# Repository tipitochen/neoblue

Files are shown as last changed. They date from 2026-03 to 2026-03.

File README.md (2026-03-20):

NEO BLUE : Direct PS5 Controller Interface for Neo Geo MVS
Nikita edition
NEO BLUE es un proyecto de hardware minimalista diseñado para habilitar el uso de mandos DualSense (PS5) en sistemas arcade SNK Neo Geo MVS.

A diferencia de otras interfaces complejas, NEO BLUE aprovecha la tolerancia de voltaje de los módulos ESP32 modernos para realizar una conexión directa y eficiente entre el Bluetooth HID y el estándar JAMMA/MVS, reduciendo la cantidad de componentes necesarios y simplificando el montaje.
Características del Proyecto:

    Conexión Directa (5V Compliant): Implementación optimizada para placas ESP32 con soporte de 5V, eliminando la necesidad de integrados de aislamiento externos.

    Dual-Core Multi-Player: Sistema de dos unidades ESP32 interconectadas por Serial (Pines 16/17) para habilitar controles independientes para Jugador 1 y Jugador 2.

    Baja Latencia: Basado en la librería Bluepad32, garantizando una respuesta casi instantánea ideal para juegos de lucha y acción.

    Interfaz Visual: Soporte para pantalla LCD 20x4 (I2C) que muestra el estado de emparejamiento, el nombre del proyecto ("NIKITA") y diagnósticos del sistema.

Ventajas de este enfoque:

    Menor Tamaño: El PCB o el cableado final es mucho más pequeño, ideal para integrar dentro de una carcasa de MVS o una Supergun.

    Simplicidad: Facilita que otros usuarios con conocimientos básicos de electrónica puedan replicar el proyecto rápidamente.

🛠️ Lista de Componentes (Bill of Materials)

Para replicar el proyecto NEO BLUE con soporte para dos jugadores y visualización de estado, necesitarás lo siguiente:
1. Microcontroladores

    2x ESP32 DevKit V1 (30 o 38 pines): Se utilizan dos unidades para gestionar ambos jugadores de forma independiente y garantizar la estabilidad del Bluetooth.

        Nota: Asegúrate de usar versiones modernas que soporten la lógica de 5V de los sistemas arcade en sus entradas/salidas.

2. Interfaz Visual

    1x Pantalla LCD 20x4 con módulo I2C: Para mostrar el estado de conexión de "Player 1" y "Player 2", además del nombre del proyecto.

        Dirección I2C común: 0x3F o 0x27.

3. Conectividad Arcade (Salidas)

    Cableado para peine JAMMA / Conector MVS: Cables para llevar las señales de los GPIO del ESP32 directamente a los pines de la placa Neo Geo.

        Direcciones: Arriba, Abajo, Izquierda, Derecha.

        Botones: A, B, C, D (y opcionalmente Select/Start).

4. Comunicación y Alimentación

    Cables de salto (Jumper Wires): Para la conexión Serial entre los dos ESP32 (Pines TX/RX 16 y 17) y la línea I2C del LCD.

    Fuente de alimentación de 5V: Puedes tomar los 5V directamente de la fuente de poder de tu sistema arcade o Supergun para alimentar los ESP32 y el LCD.

5. Periféricos (Mandos)

    1 o 2 Mandos Sony DualSense (PS5): Compatibles mediante la librería Bluepad32 integrada en el código.

Diagrama de conexiones :
<p align="center">
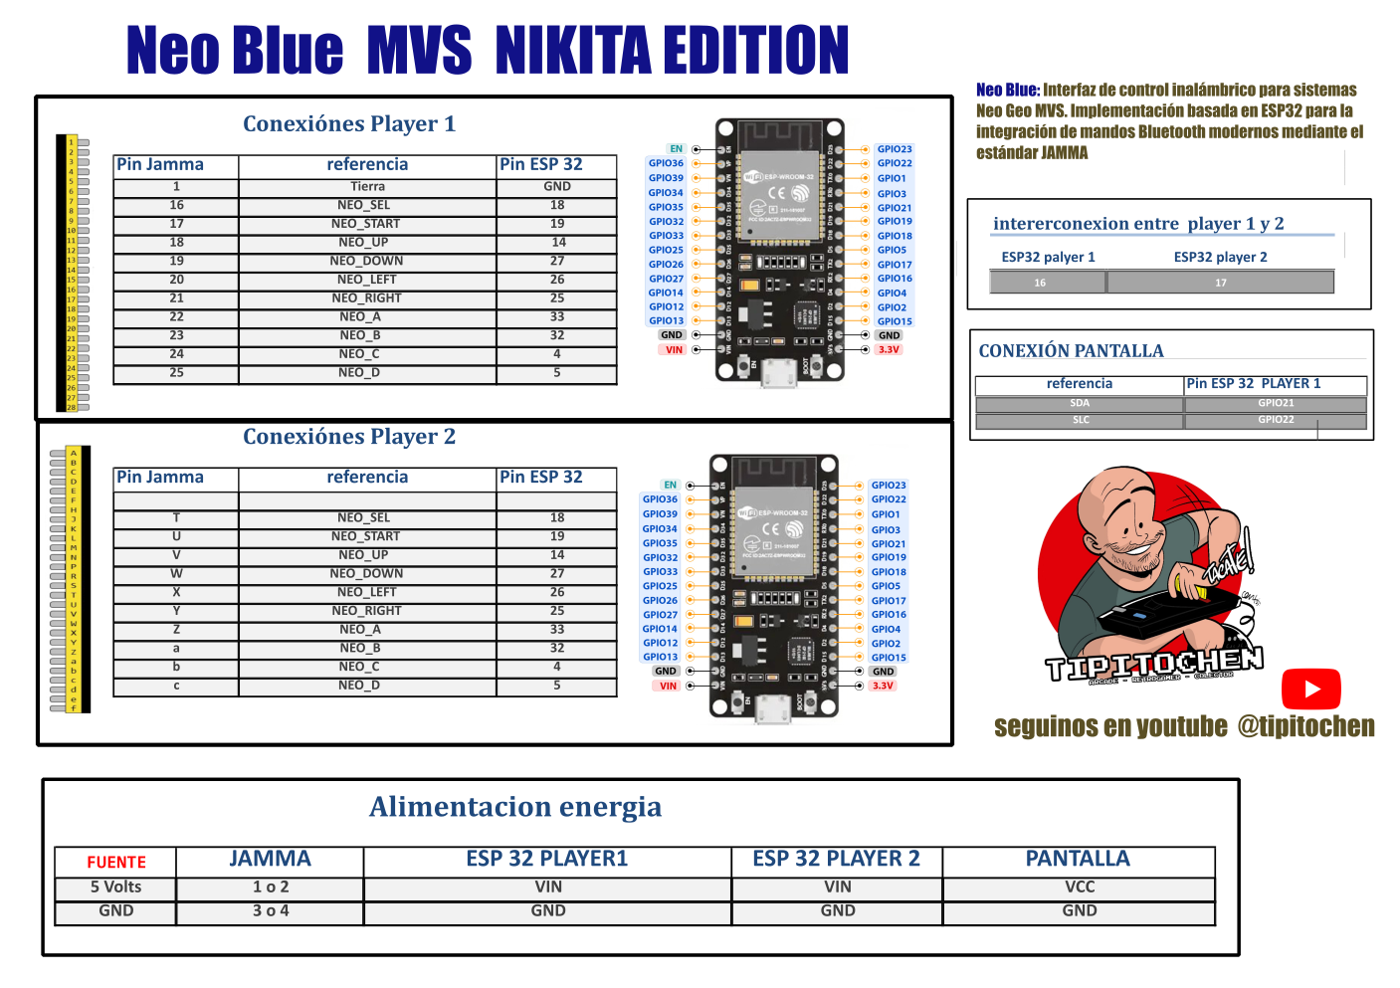
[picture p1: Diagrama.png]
Diagrama Neo Blue
  
</p>

💻 Software y Librerías Requeridas

Para compilar este proyecto en el IDE de Arduino, asegúrate de tener instaladas las siguientes dependencias:

    Bluepad32: La librería principal para la gestión de los mandos DualSense/PS5 vía Bluetooth.

    LiquidCrystal_I2C: Para el manejo de la pantalla LCD 20x4 (Dirección 0x3F).

    Wire.h: Librería estándar para la comunicación I2C entre el ESP32 y el display.

### 🤝 Agradecimientos
Este proyecto utiliza la excelente librería **[Bluepad32](https://github.com/ricardoquesada/bluepad32)** de **Ricardo Quesada**. Gracias a su trabajo en el stack de Bluetooth, es posible conectar mandos modernos a sistemas clásicos.
    
📸 Galería del Proyecto

| | |
|:---:|:---:|
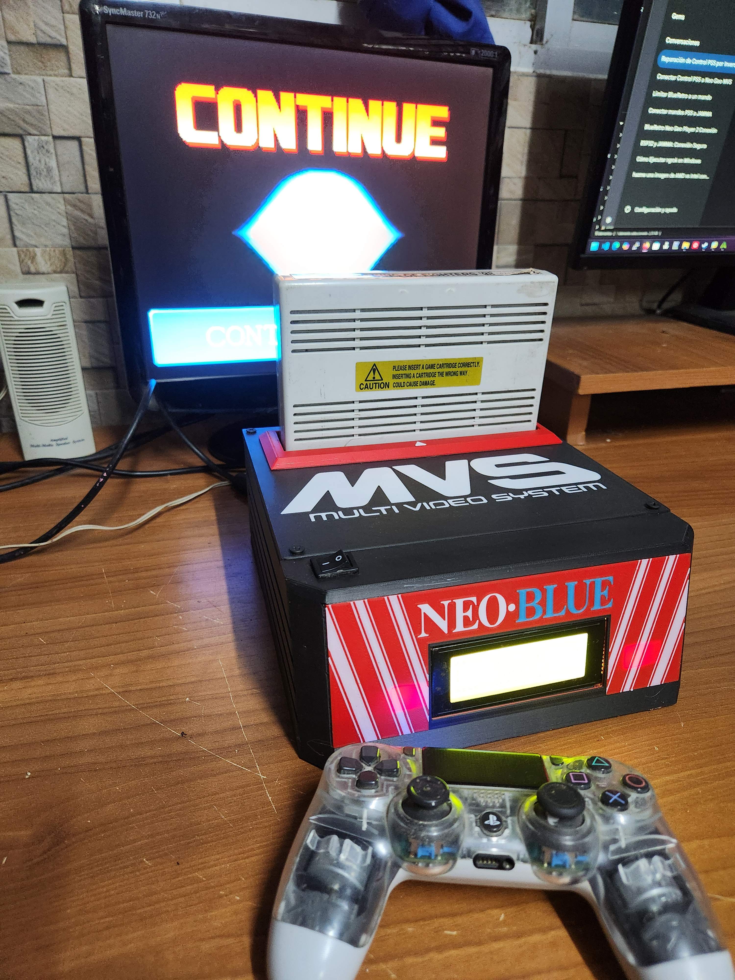
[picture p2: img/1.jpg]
Sistema en acción
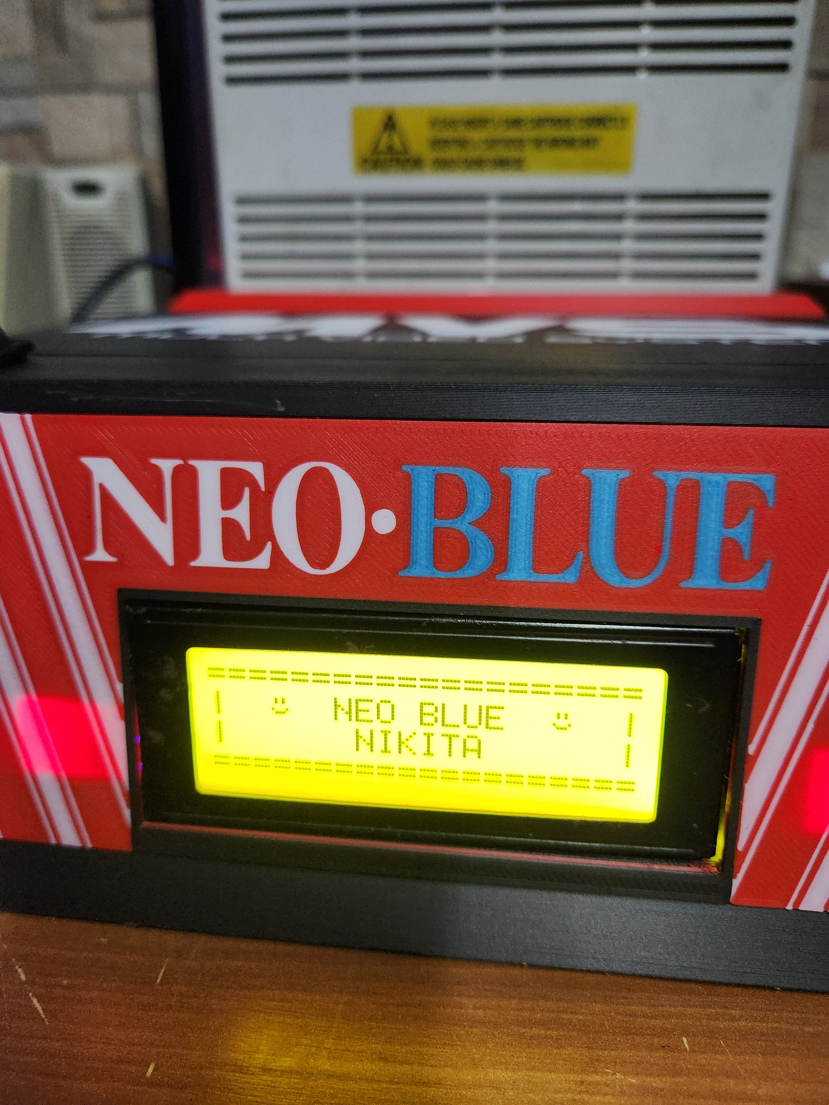
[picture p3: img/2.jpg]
Pantalla de Inicio
|  <br> **Setup Completo:** Consola MVS custom con mando DualSense. |  <br> **Bienvenida:** Interfaz LCD personalizada con el nombre **NIKITA**. |
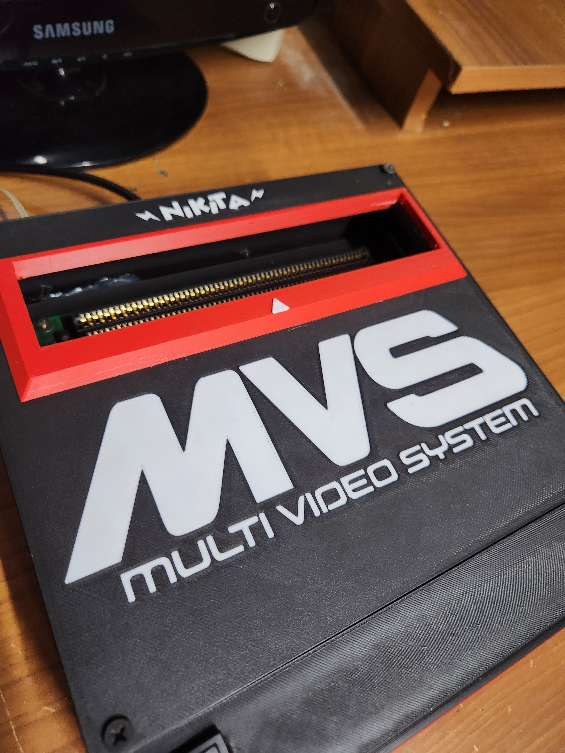
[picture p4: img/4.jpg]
Slot de Cartuchos
| Vista Superior <br> **Estética MVS:** Diseño frontal con colores clásicos de SNK. |  <br> **Detalle del Slot:** Acabado de la carcasa superior. |
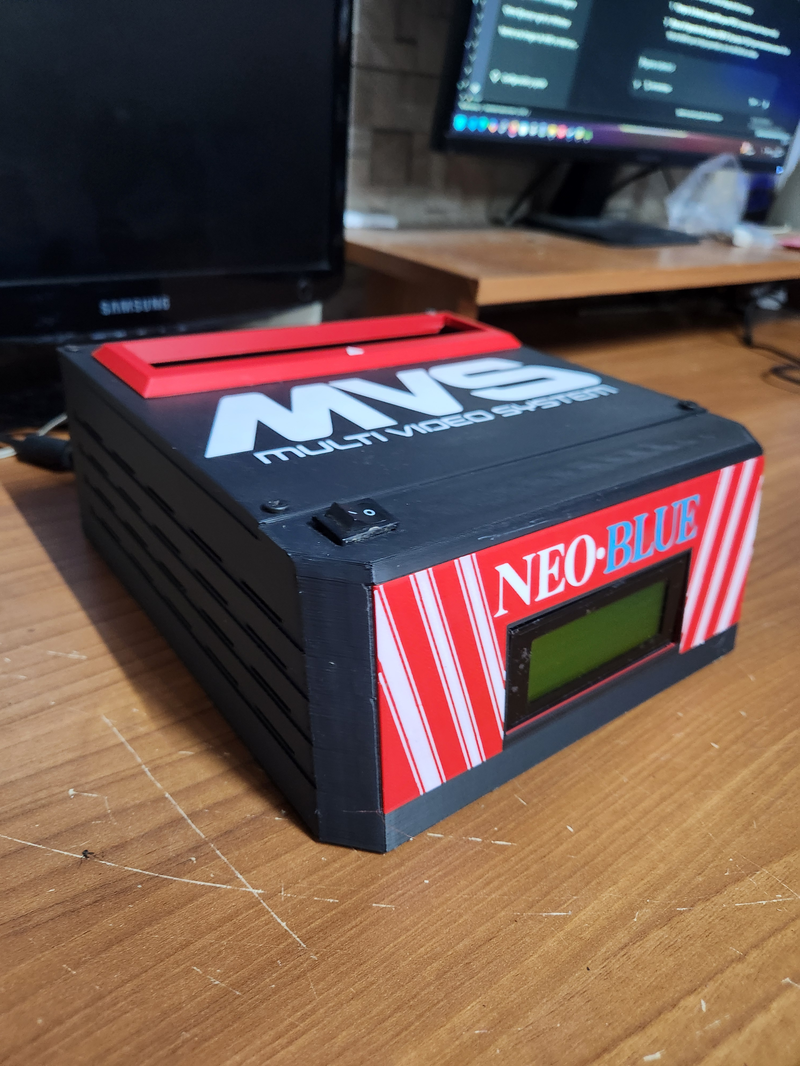
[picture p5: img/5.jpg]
Perfil de la Consola
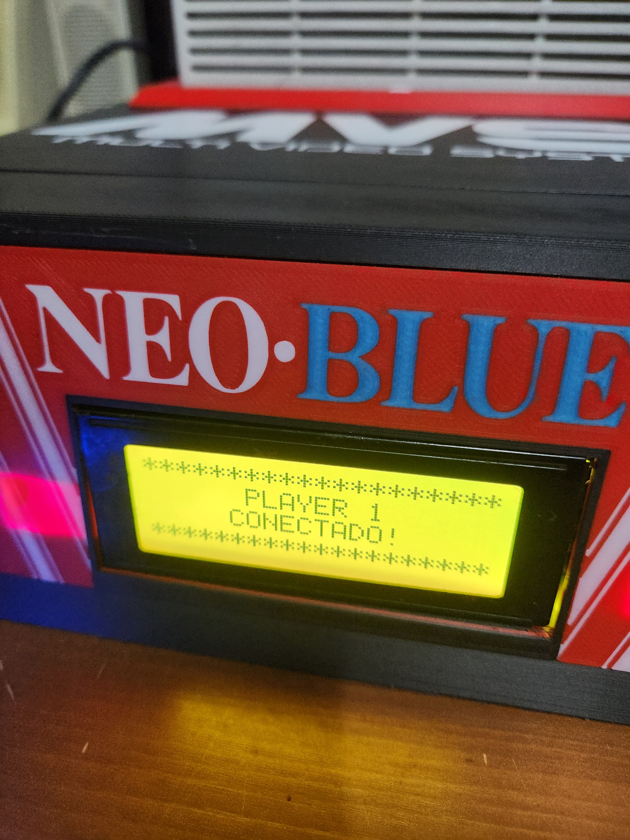
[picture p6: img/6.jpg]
Estado del Jugador
|  <br> **Diseño Compacto:** Vista lateral mostrando el interruptor. |  <br> **Conectividad:** Confirmación de **PLAYER 1 CONECTADO**. |

---
📺 Casi Tutoriales y Demostraciones

Si quieres ver el proyecto Neo Blue funcionando en una placa Neo Geo MVS real o necesitas una guía paso a paso sobre el montaje, visita mi canal de YouTube:

👉 Canal Oficial: Tipitochen en YouTube
Ver Video Neo Blue (https://www.youtube.com/watch?v=wPD0EBTdPX4)

y si señores ... tenia que ser .. Nikita!

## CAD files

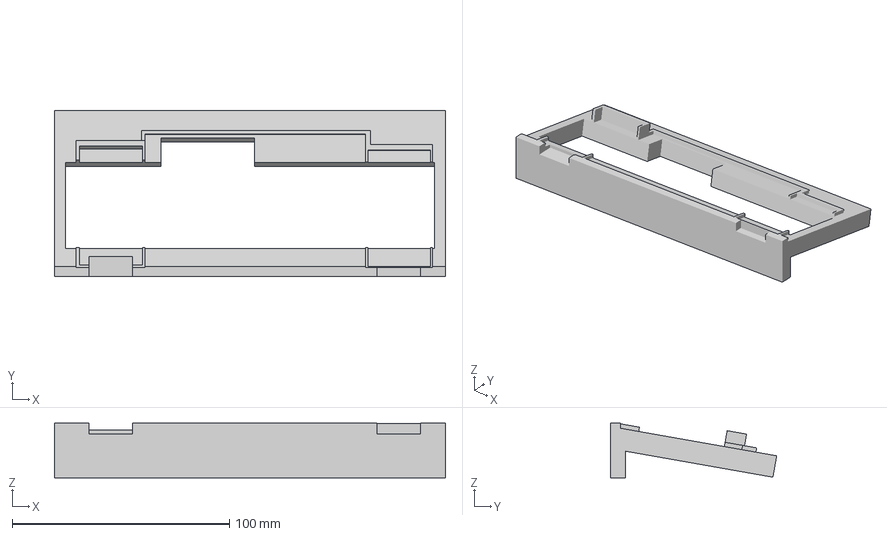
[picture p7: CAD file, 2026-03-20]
Diseño 3mf para imprimir/Soporte dis.3mf
180.0 x 76.6 x 25.2 mm

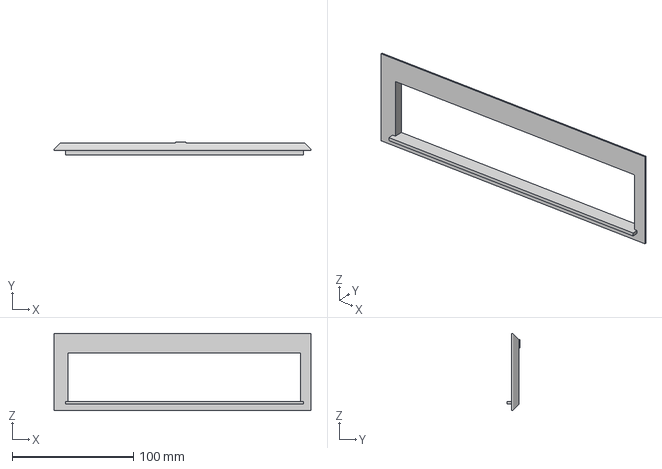
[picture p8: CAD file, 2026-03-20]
Diseño 3mf para imprimir/borde cartuch.3mf
212.3 x 11.0 x 63.7 mm

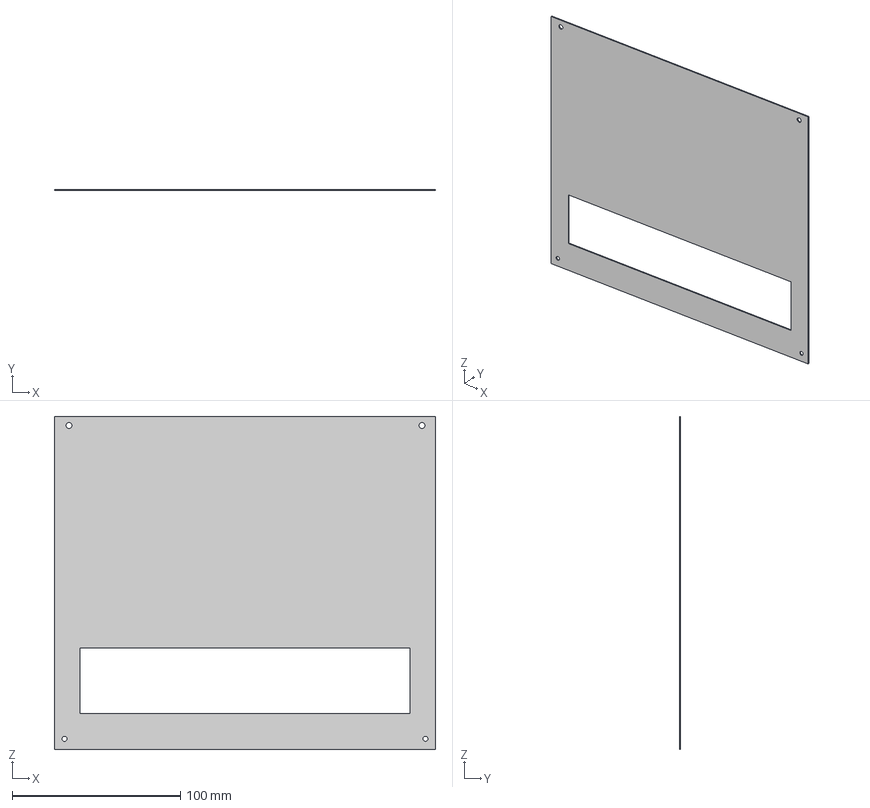
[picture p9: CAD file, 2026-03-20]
Diseño 3mf para imprimir/test3.3mf
226.5 x 0.8 x 198.0 mm

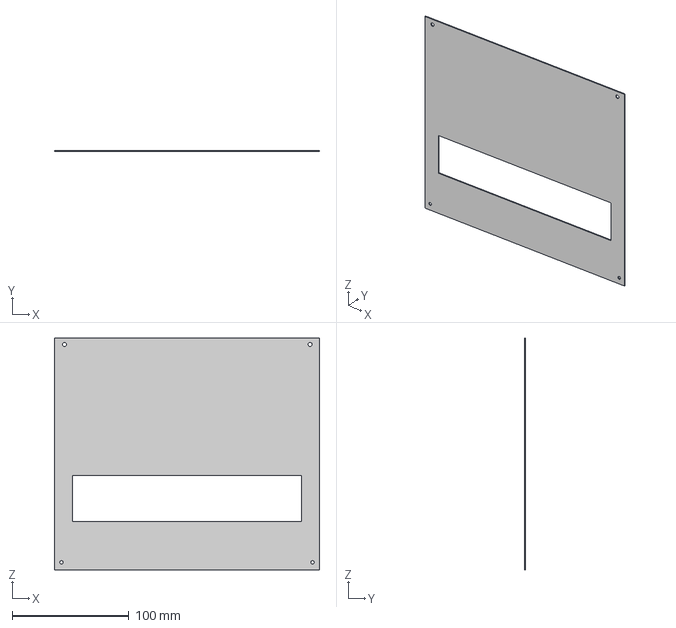
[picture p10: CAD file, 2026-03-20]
Diseño 3mf para imprimir/test 2.3mf
226.5 x 1.00 x 198.0 mm

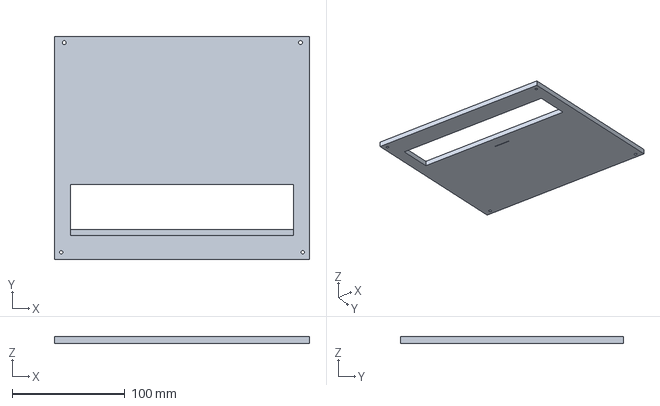
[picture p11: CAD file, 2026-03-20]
Diseño 3mf para imprimir/Tapa superior.3mf
226.5 x 198.0 x 5.80 mm

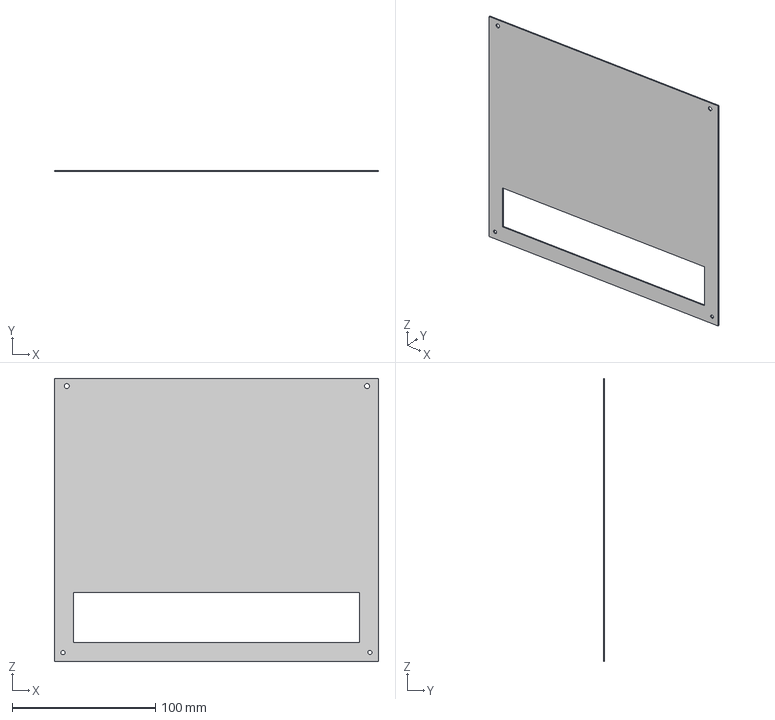
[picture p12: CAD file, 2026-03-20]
Diseño 3mf para imprimir/test.3mf
226.5 x 1.00 x 198.0 mm

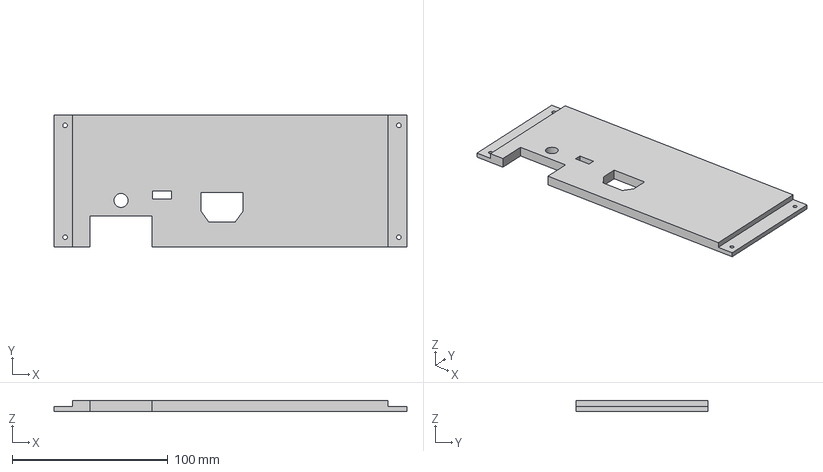
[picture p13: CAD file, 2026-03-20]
Diseño 3mf para imprimir/Tapa trasera.3mf
226.5 x 85.0 x 7.00 mm

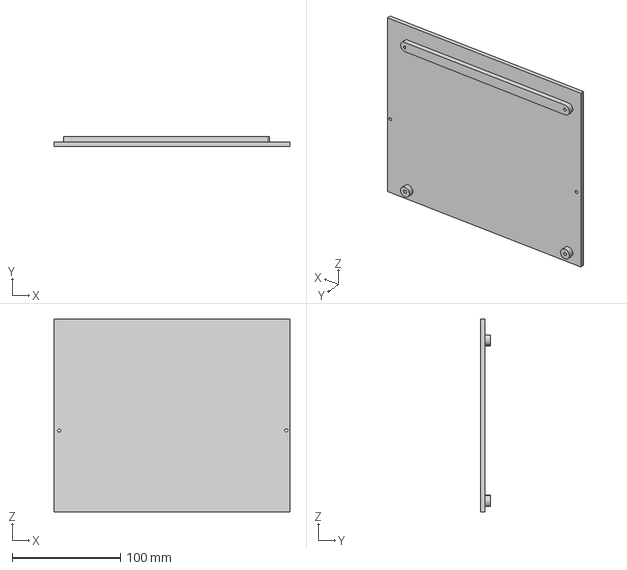
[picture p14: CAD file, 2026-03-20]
Diseño 3mf para imprimir/Segundo piso.3mf
218.2 x 9.00 x 178.3 mm

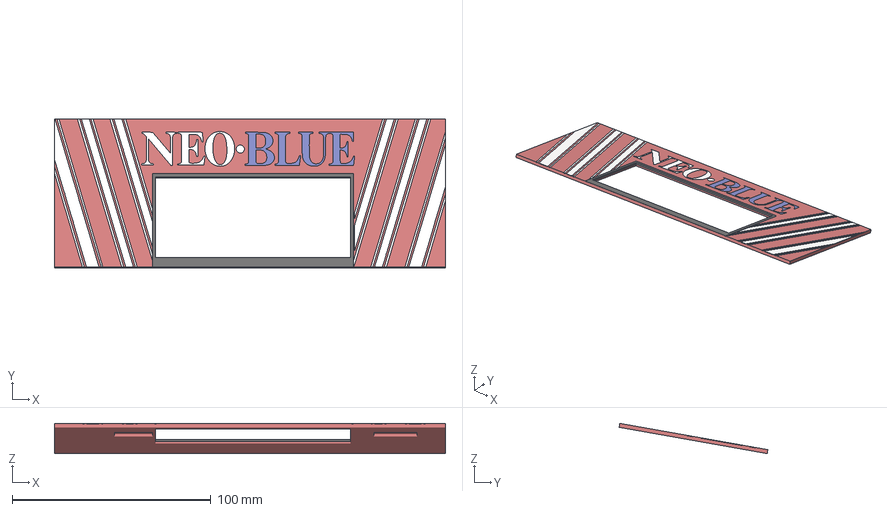
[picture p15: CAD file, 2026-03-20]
Diseño 3mf para imprimir/Frontal.3mf
196.5 x 74.8 x 15.2 mm
Cuerpo53
Cuerpo54
Cuerpo55
Cuerpo56
Cuerpo57
Cuerpo58
Cuerpo59
Cuerpo60
Cuerpo61
Cuerpo62
Cuerpo63
Cuerpo64
Cuerpo65
Cuerpo66
Cuerpo67
Cuerpo68
Cuerpo69
Cuerpo70
E
Front
L
b
borde
n
o2
ue

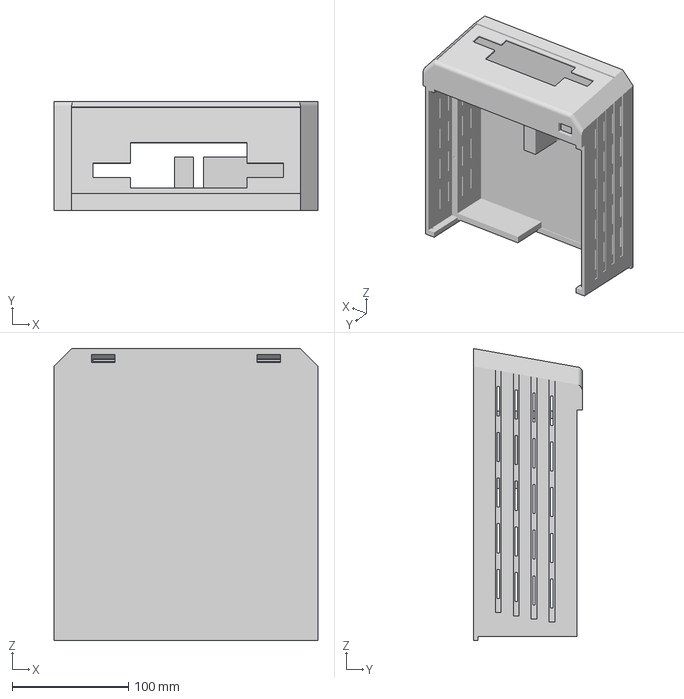
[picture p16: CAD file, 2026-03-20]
Diseño 3mf para imprimir/Caja.3mf
226.5 x 94.0 x 250.8 mm

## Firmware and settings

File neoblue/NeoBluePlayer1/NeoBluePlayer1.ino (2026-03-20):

#include <Wire.h>
#include <LiquidCrystal_I2C.h>
#include <Bluepad32.h>

// --- PINES MVS P1 ---
#define NEO_UP    14
#define NEO_DOWN  27
#define NEO_LEFT  26
#define NEO_RIGHT 25
#define NEO_A     33
#define NEO_B     32
#define NEO_C      4   
#define NEO_D      5   
#define NEO_START 19
#define NEO_SEL   18
#define LED_PLACA  2 

LiquidCrystal_I2C lcd(0x3F, 20, 4);
const int stickThreshold = 350;
ControllerPtr myController = nullptr;

byte caraFeliz[8] = {
  B00000, B01010, B01010, B00000, B10001, B01110, B00000, B00000
};

void mostrarNeoBlue() {
    lcd.clear();
    lcd.setCursor(0, 0);
    lcd.print("====================");
    lcd.setCursor(0, 3);
    lcd.print("====================");
    lcd.setCursor(0, 1);
    lcd.print("|  ");
    lcd.write(0);
    lcd.print("  NEO BLUE  ");
    lcd.write(0);
    lcd.print("  |");
    lcd.setCursor(0, 2);
    lcd.print("|      NIKITA      |");
}

void alertaConexion(String p) {
    for(int i=0; i<4; i++) {
        lcd.clear();
        lcd.backlight();
        lcd.setCursor(0, 0);
        lcd.print("********************");
        int posP = (20 - p.length()) / 2;
        lcd.setCursor(posP, 1);
        lcd.print(p);
        
        lcd.setCursor(5, 2);
        lcd.print("CONECTADO!");
        
        lcd.setCursor(0, 3);
        lcd.print("********************");
        delay(300);
        lcd.noBacklight();
        delay(100);
    }
    lcd.backlight();
    mostrarNeoBlue();
}

void onConnectedController(ControllerPtr ctl) {
    if (myController != nullptr) { ctl->disconnect(); return; }
    myController = ctl;
    ctl->setRumble(0xc0, 0x40);
    alertaConexion("PLAYER 1");
}

void onDisconnectedController(ControllerPtr ctl) {
    if (myController == ctl) {
        myController = nullptr;
        int p[] = {14, 27, 26, 25, 33, 32, 4, 5, 19, 18};
        for(int i=0; i<10; i++) digitalWrite(p[i], HIGH);
        digitalWrite(LED_PLACA, LOW);
        mostrarNeoBlue(); 
    }
}

void setup() {
    Serial.begin(115200);
    // RX=16 (donde sueldas el cable), TX=17
    Serial2.begin(115200, SERIAL_8N1, 16, 17);

    lcd.init();
    lcd.backlight();
    lcd.createChar(0, caraFeliz);
    mostrarNeoBlue();

    int pines[] = {14, 27, 26, 25, 33, 32, 4, 5, 19, 18, LED_PLACA};
    for(int i=0; i<11; i++) {
        pinMode(pines[i], OUTPUT);
        if(pines[i] != LED_PLACA) digitalWrite(pines[i], HIGH);
    }
    BP32.setup(&onConnectedController, &onDisconnectedController);
}

void loop() {
    BP32.update();
    if (myController && myController->isConnected()) {
        uint16_t b = myController->buttons();
        uint8_t d = myController->dpad();
        uint8_t m = myController->miscButtons();
        int32_t x = myController->axisX();
        int32_t y = myController->axisY();
        digitalWrite(NEO_UP,    !((d & 0x01) || (y < -stickThreshold)));
        digitalWrite(NEO_DOWN,  !((d & 0x02) || (y > stickThreshold)));
        digitalWrite(NEO_LEFT,  !((d & 0x08) || (x < -stickThreshold)));
        digitalWrite(NEO_RIGHT, !((d & 0x04) || (x > stickThreshold)));
        digitalWrite(NEO_A,     !(b & 0x0001));
        digitalWrite(NEO_B,     !(b & 0x0002));
        digitalWrite(NEO_C,     !(b & 0x0004));
        digitalWrite(NEO_D,     !(b & 0x0008));
        digitalWrite(NEO_START, !(m & 0x04));
        digitalWrite(NEO_SEL,   !(m & 0x02));
        digitalWrite(LED_PLACA, HIGH);
    } else {
        digitalWrite(LED_PLACA, LOW);
    }

    if (Serial2.available() > 0) {
        if (Serial2.read() == 'C') {
            alertaConexion("PLAYER 2");
        }
    }
}
